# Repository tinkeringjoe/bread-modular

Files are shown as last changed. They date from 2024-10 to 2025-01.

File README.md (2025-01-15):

# Bread Modular
Bread Modular is an open-source hardware modular synthesizer format designed to be minimalistic and cost-effective.

Bread Modular
### Key Features

* **Modular Design:** Just like Eurorack
* **USB-Powered:** It can be portable
* **Minimal Design:** Cost Effective
* **Modular MIDI Support:** Use MIDI to communicate between modules (still supports CV & Gate)
* **Analog and Digital Signal Paths:** It’s your choice 
* **Diverse Built-in Modules:** Includes a wide range of pre-designed modules
* **Configurable Digital Modules:** Supports both voice and CV (uses AtTiny 1616 or ESP32)
* **Fully Open Source:** Including schematics, PCB designs, and code
* **Ease of Customization:** Enables straightforward creation of custom modules tailored to specific needs.
* **No Case Required:** Can be used directly on a breadboard or mounted on a simple base module.

## Table of Contents

* [Specification](https://github.com/bread-modular/bread-modular/wiki/Specification)
* [Common Parts](https://github.com/bread-modular/bread-modular/wiki/Common-Parts)
* [Modules](https://github.com/bread-modular/bread-modular/wiki/Modules)

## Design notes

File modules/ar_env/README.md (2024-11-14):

# AR ENV

A Simple Attack/Release Envelope.

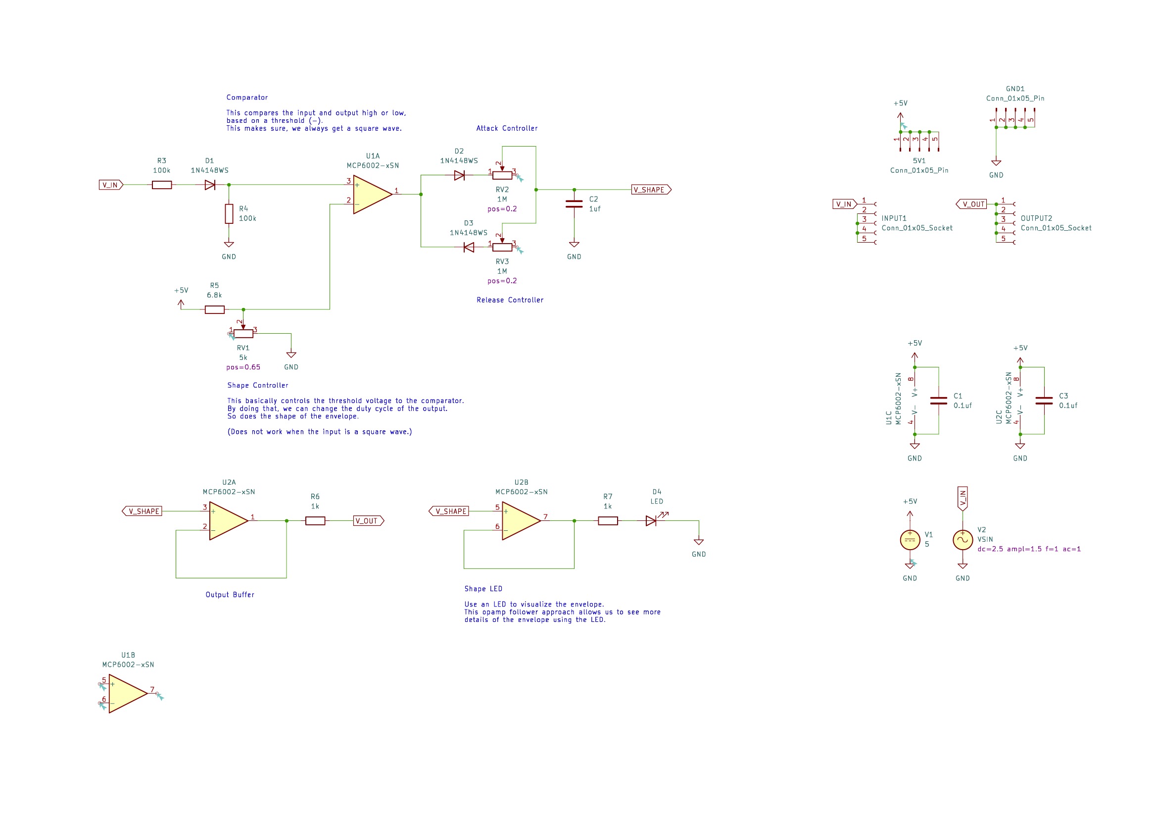
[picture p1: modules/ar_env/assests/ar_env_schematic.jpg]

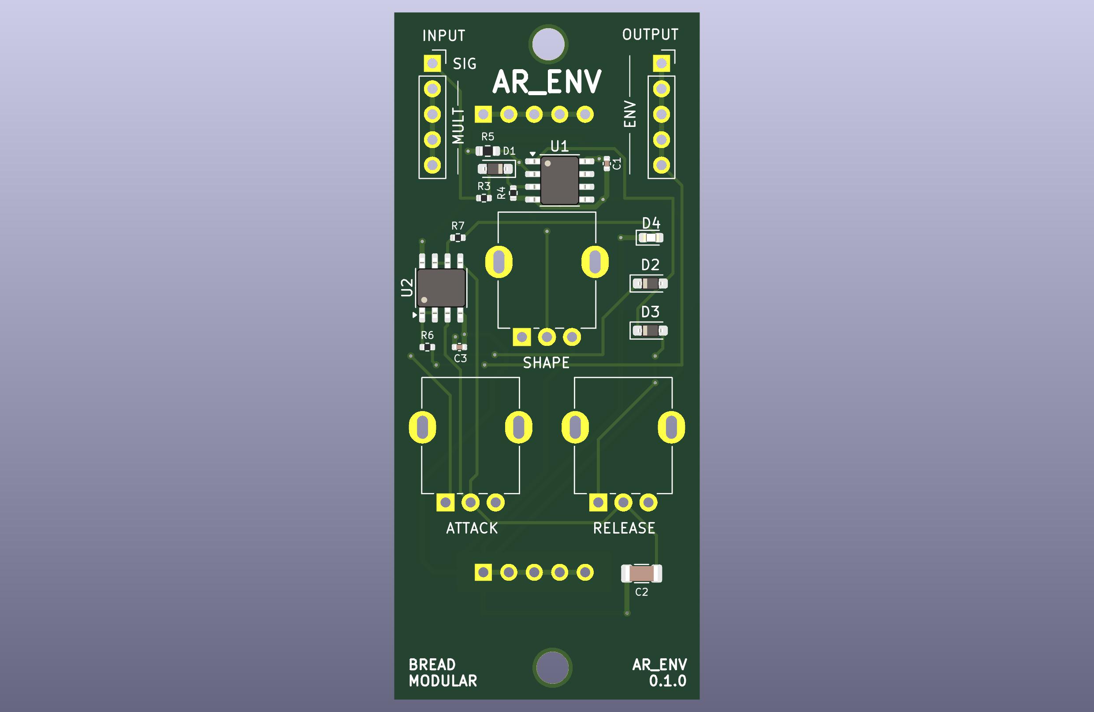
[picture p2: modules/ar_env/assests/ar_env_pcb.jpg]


This has three controls:

* Attack
* Release
* Shape - Controls the duty cycle. Only works when the "SIG" input is a triangle signal. 

> Make sure to keep the Shape at pos=0.5 when using the square wave inputs.

## Known Errors

* When the Attack & Release is close to zero, this module leaks some pops to the ground.
(So, it will pick up by the line-out)
* When the input is above 5Hz, it's very hard to control Attack & Release. (We need to wiggle between pos=0.0 & pos=0.2)
* Using with JVCA gives more controls, but it will be confusing sometimes. Especially JVCA has a built-in delay effect for changes.
(It could be a feature too)
A simple Vactral based VCA would fix it. (V2CA)

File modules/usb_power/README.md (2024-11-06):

# USB_Power

A simple power source from USB.

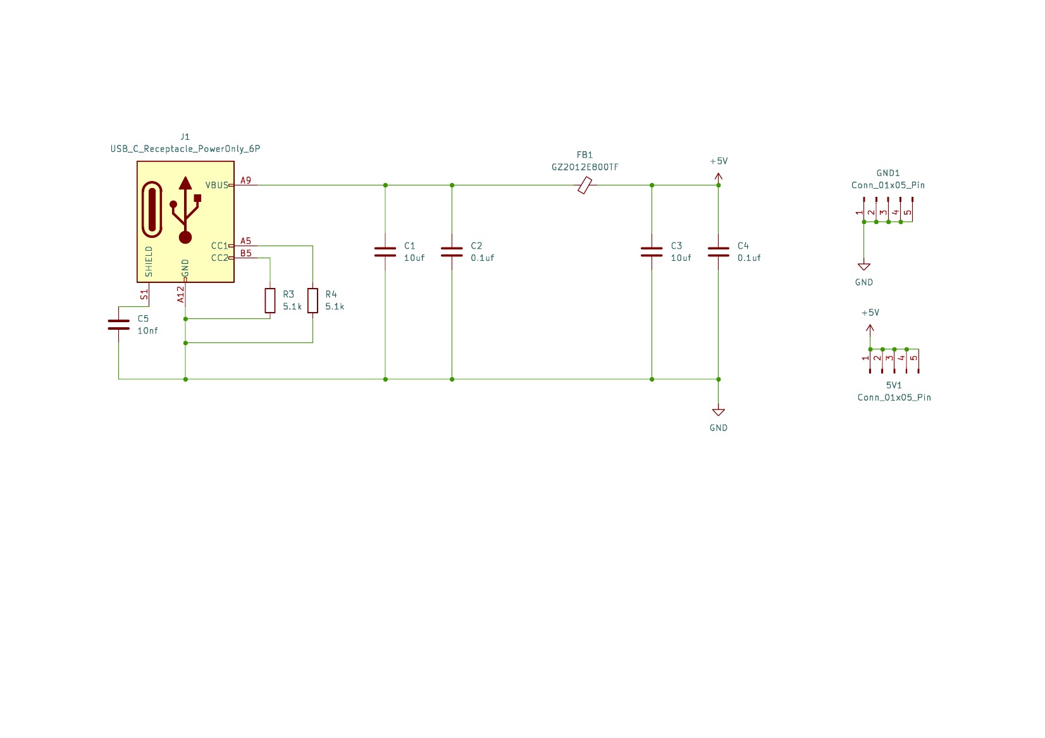
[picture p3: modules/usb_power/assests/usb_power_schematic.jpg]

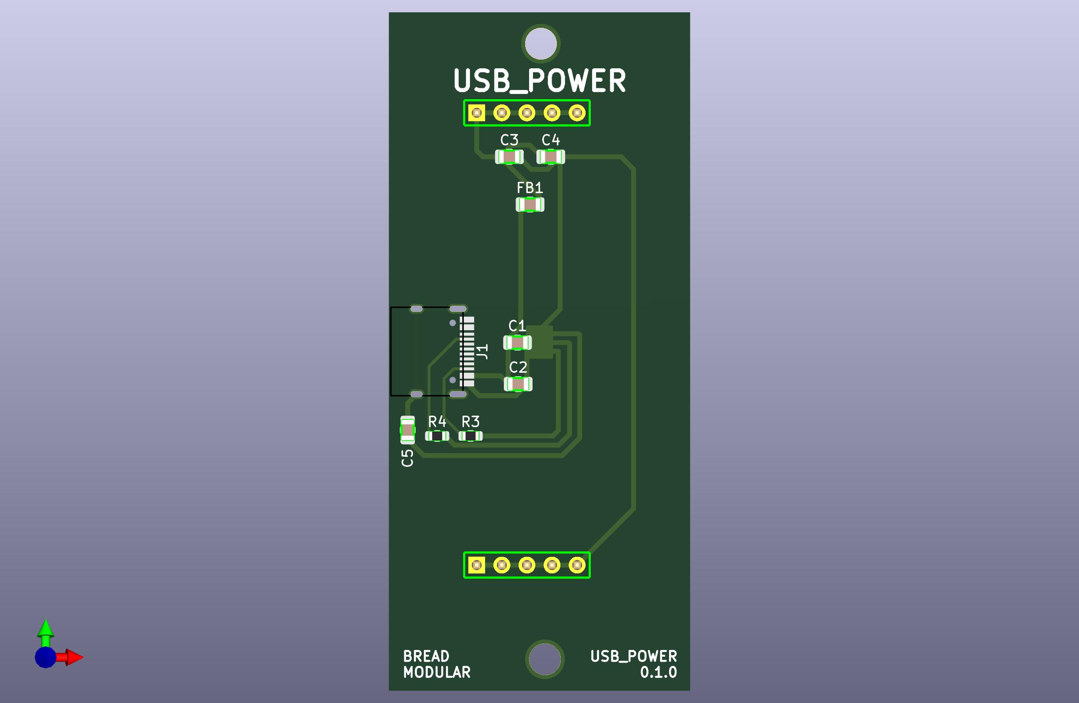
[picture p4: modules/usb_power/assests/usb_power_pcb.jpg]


## Usage

This plug a USB-C and now we have power to the system.<br/>
This makes is not only to get power from computer, but using bunch of power source including your phone. This will be the only power source we'll ever need.

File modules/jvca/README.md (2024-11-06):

# JVCA

JFET based VCA with bias and gain control.

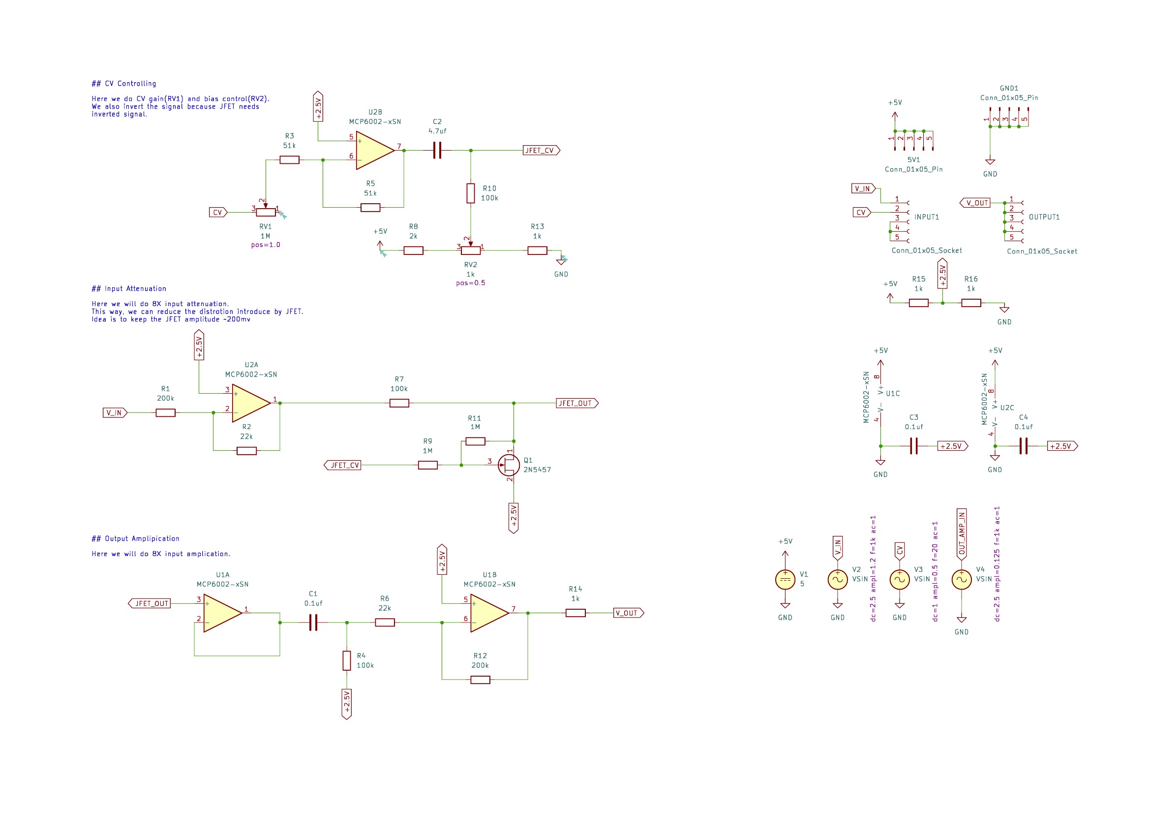
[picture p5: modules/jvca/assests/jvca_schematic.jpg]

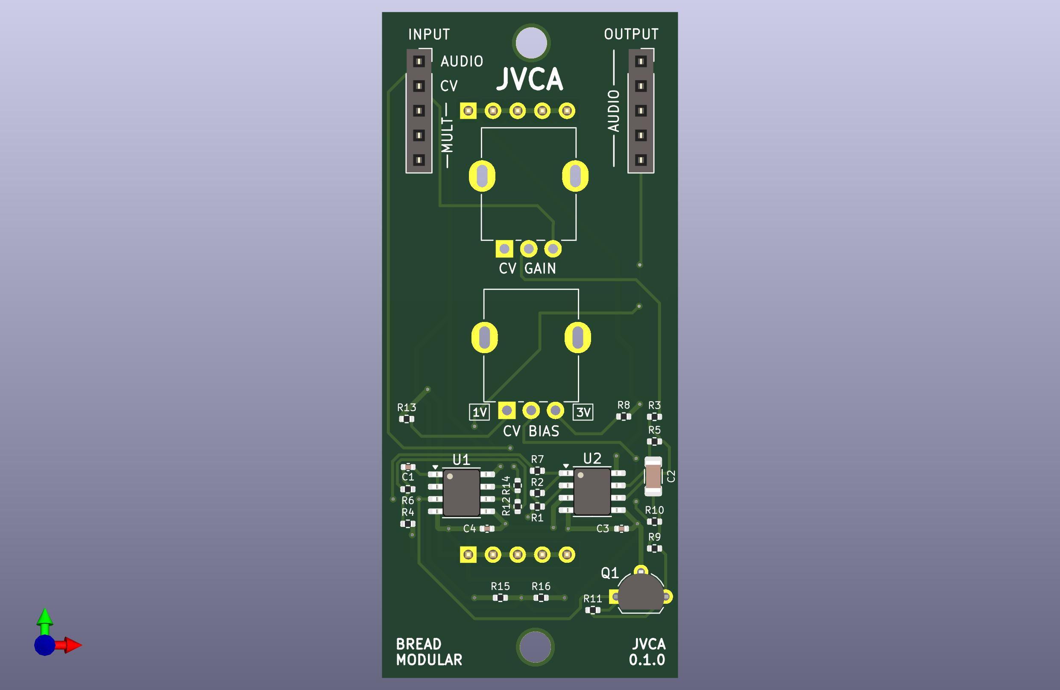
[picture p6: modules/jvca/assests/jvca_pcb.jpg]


## Usage

* We can control CV gain with the "CV GAIN" RV and minumum gain is 0.05 and maximum is 1.
* CV bias RV will change the CV bias from 1V to 3V range.
  * If it's 1V, audio is audible even with CV change.
  * If it's 3V, audio is not audible

* If we center the CV around 2V, 500mv amplitude is enough to cut through the audio.
* But we can play with these values to get interesting results

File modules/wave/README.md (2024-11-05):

# Wave

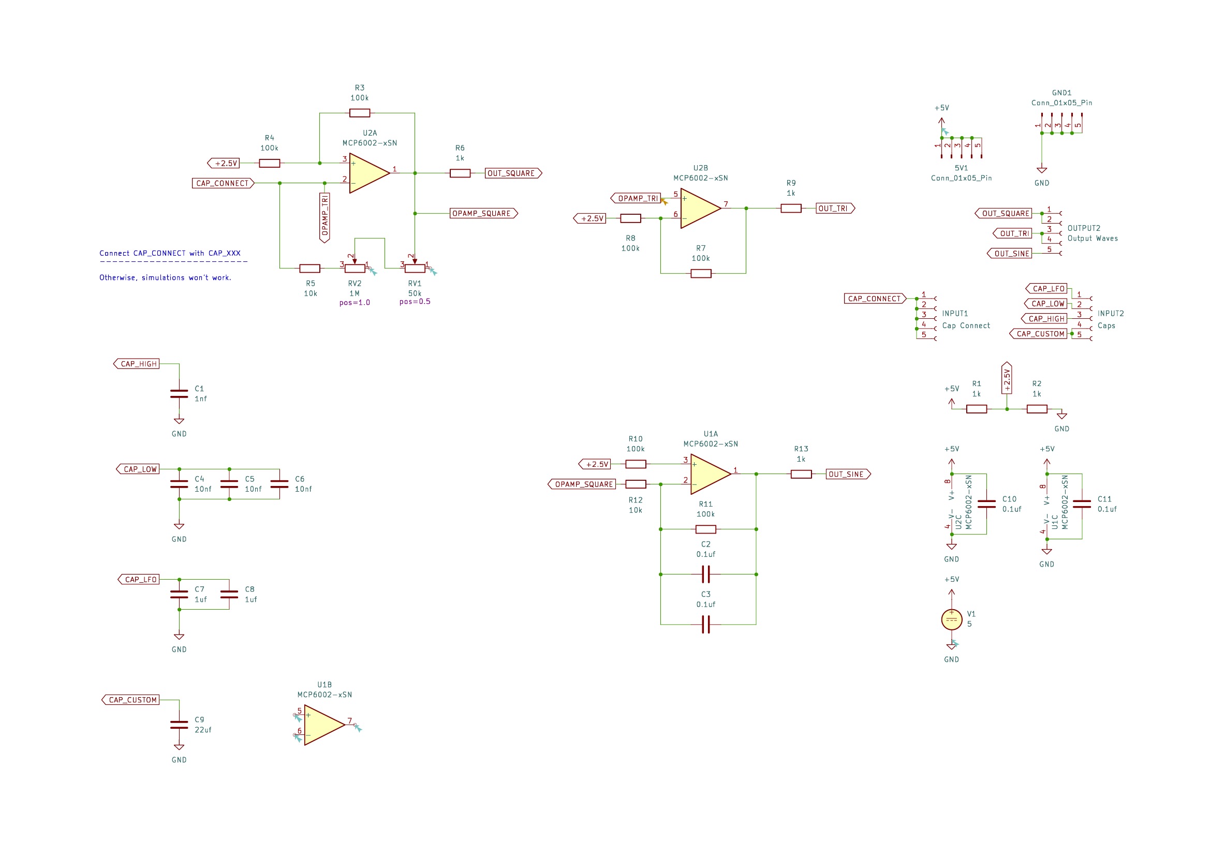
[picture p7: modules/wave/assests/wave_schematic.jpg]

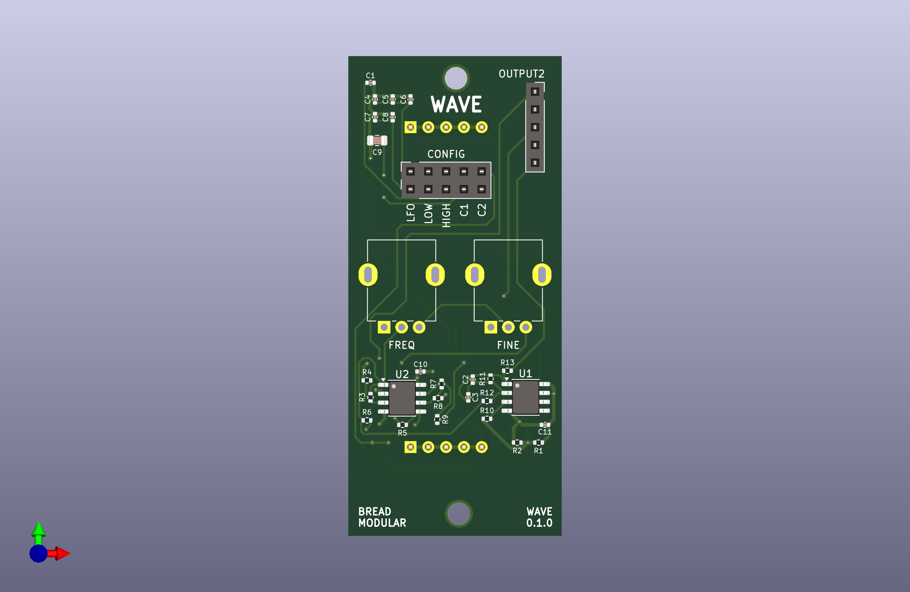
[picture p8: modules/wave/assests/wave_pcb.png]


A Simple Waveform generator based on opamp relaxation oscillators. It can generate:

* Square
* Triangle 
* Sine (only upword 45Hz)

## Configurations

Before we use this module, we need to configure and select the frequence range via the config jumping panel.

Here are the frequency ranges:

* LFO - 0.22Hz to 22Hz
* LOW - 15Hz to 1.5kHz
* HIGH - 227Hz to 22kHz
* C1 & C2 - Add custom capacitors
  (Resistance => Min: 10k, Max: 1M)

## Usage

You can select the frequency using "FREQ" potentiometer which is 1M ohms. Then you can fine tune it via the 50k ohms "FINE" potentiometer.

(Turning clockwise reduces the resistance)

## Notes

* Does not produce any results, when it's not configured
* Triangle waveform is appoximated & it's not a pure triangle
* Sine wave got distroted when the frequncy is below 45Hz
* Sine wave will be attenuated as the freq increases
* No voltage control input or modulation is supported

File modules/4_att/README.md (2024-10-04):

# 4_ATT

This is a 4 channel passive attenuator. 

<p float="left">
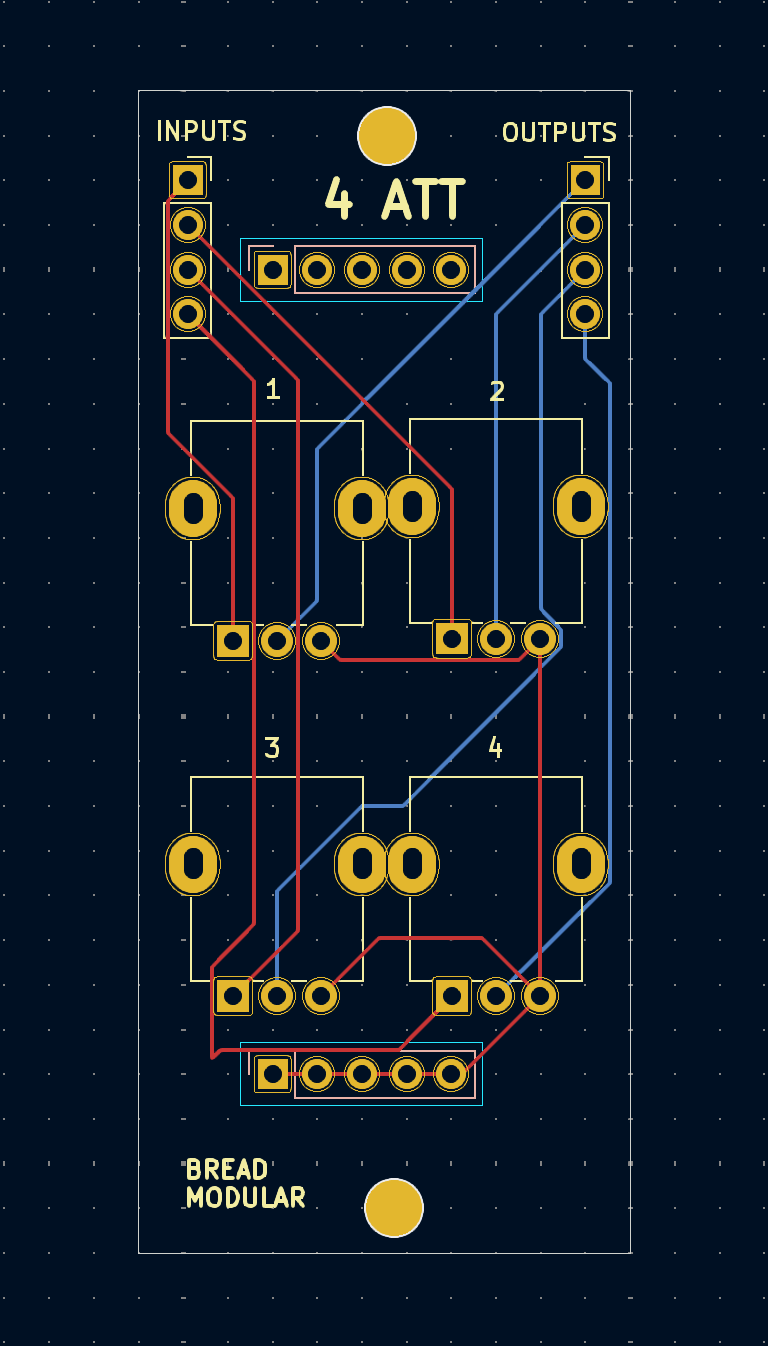
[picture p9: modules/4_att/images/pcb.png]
  
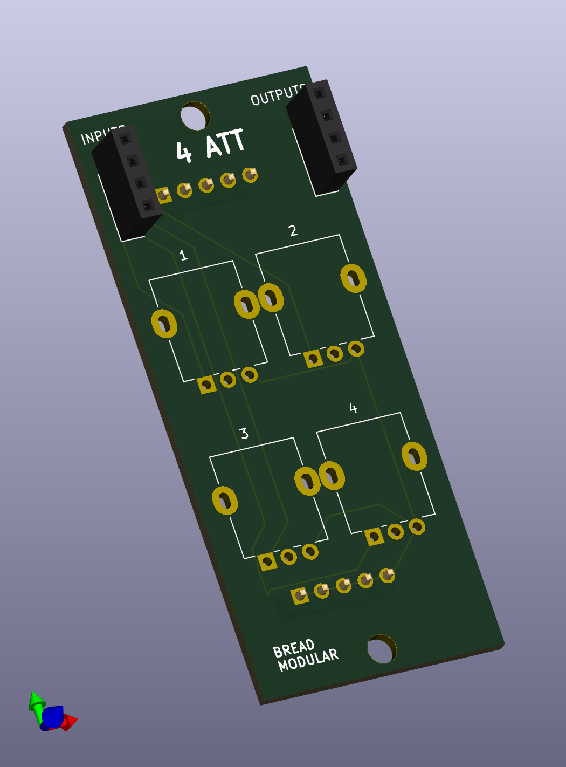
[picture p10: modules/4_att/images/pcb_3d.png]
   
</p>

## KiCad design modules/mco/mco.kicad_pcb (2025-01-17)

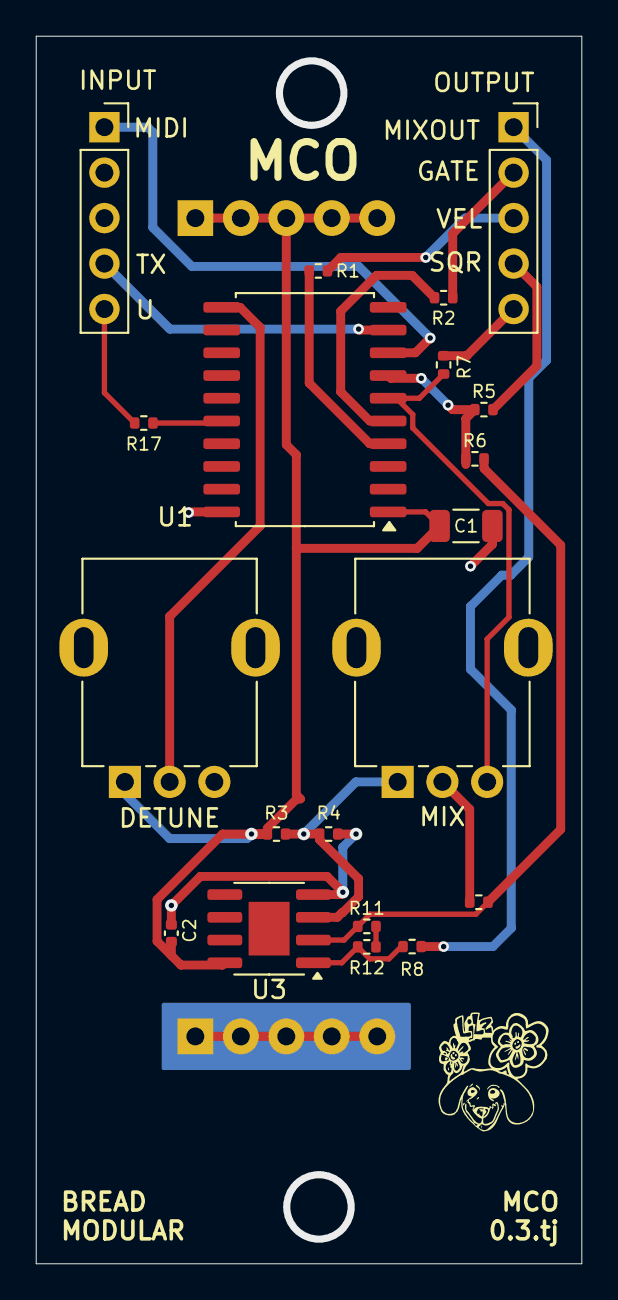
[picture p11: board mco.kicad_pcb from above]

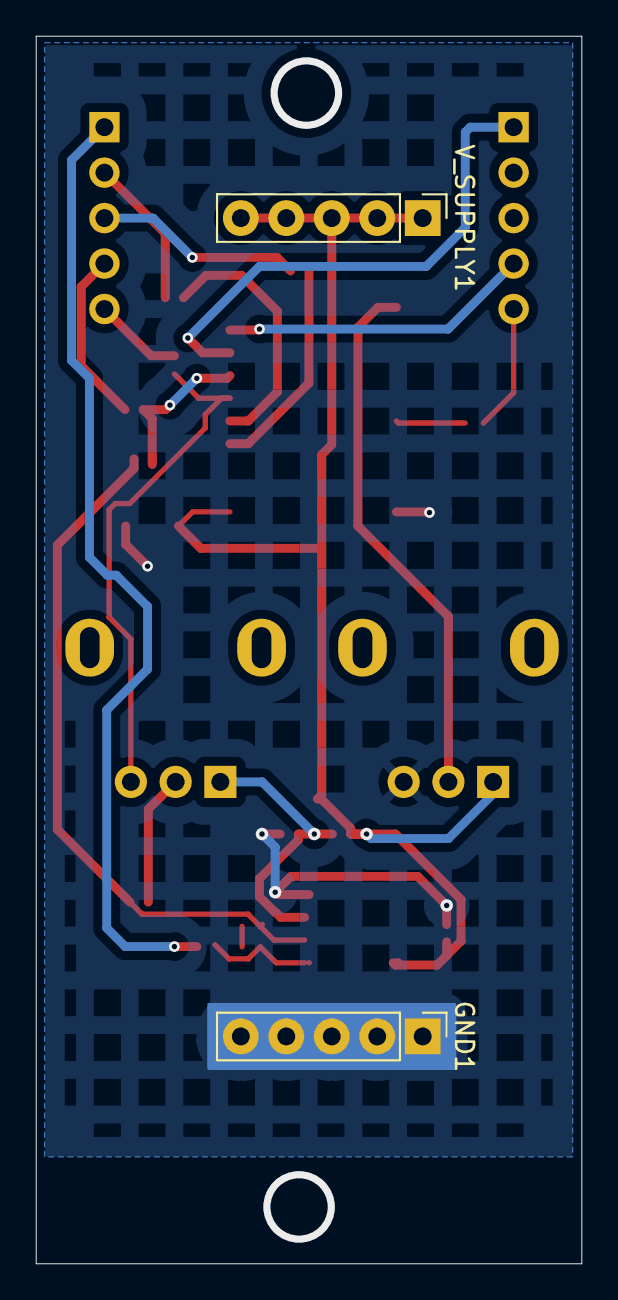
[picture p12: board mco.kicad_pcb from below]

Board: 2 copper layers, 30.5 x 68.6 mm, 22 parts (2 on the bottom side), 21 nets.

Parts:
C1: 100uf; C_1206_3216Metric
C2: 0.1uf; C_0402_1005Metric
GND1: Conn_01x05_Pin; Power_Connector
INPUT1: Conn_01x05_Socket; PinSocket_1x05_P2.54mm_Vertical
OUTPUT1: Conn_01x05_Socket; PinSocket_1x05_P2.54mm_Vertical
R1, R2, R3, R4, R5, R7, R8: 1k; R_0402_1005Metric
R6, R10: 1M; R_0402_1005Metric
R11, R12: 200k; R_0402_1005Metric
R17: 4.7k; R_0402_1005Metric
RV1, RV2: 50k; Potentiometer_RV09
U1: ATtiny1616-S; SOIC-20W_7.5x12.8mm_P1.27mm
U3: MCP6002-xSN; SOIC-8-1EP_3.9x4.9mm_P1.27mm_EP2.29x3mm
V_SUPPLY1: Conn_01x05_Pin; Power_Connector

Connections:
DETUNED_OUT: OUTPUT1.5, R7.2
DETUNED_TONE: R7.1, RV2.3, U1.6 (PB5)
FUNDAMENTAL_TONE: R5.1, R6.1, U1.7 (PB4)
GATE: OUTPUT1.2, R2.2
GND: C1.1, C2.2, GND1.1, GND1.2, GND1.3, GND1.4, GND1.5, R4.2, RV1.3, U1.20 (GND), U3.4 (V-)
MIDI: INPUT1.1, U1.8 (PB3)
MIX_OUT: OUTPUT1.1, R8.2
unnamed: R10.1, RV2.2
unnamed: R11.2, R12.1
unnamed: R8.1, R12.2, U3.1
unnamed: R1.1, U1.4 (PA6)
unnamed: R2.1, U1.5 (PA7)
unnamed: R17.1, U1.16 (~RESET/PA0)
unnamed: R6.2, R10.2, R11.1, U3.2 (-)
SQUARE_OUT: OUTPUT1.4, R5.2
TX: INPUT1.4, U1.9 (PB2)
UDPI: INPUT1.5, R17.2
VELOCITY: OUTPUT1.3, R1.2
V_DETUNED: RV1.2, U1.11 (PB0)
V_MID: R3.2, R4.1, RV2.1, U3.3 (+)
V_SUPPLY: C1.2, C2.1, R3.1, RV1.1, U1.1 (VCC), U3.8 (V+), V_SUPPLY1.1, V_SUPPLY1.2, V_SUPPLY1.3, V_SUPPLY1.4, V_SUPPLY1.5

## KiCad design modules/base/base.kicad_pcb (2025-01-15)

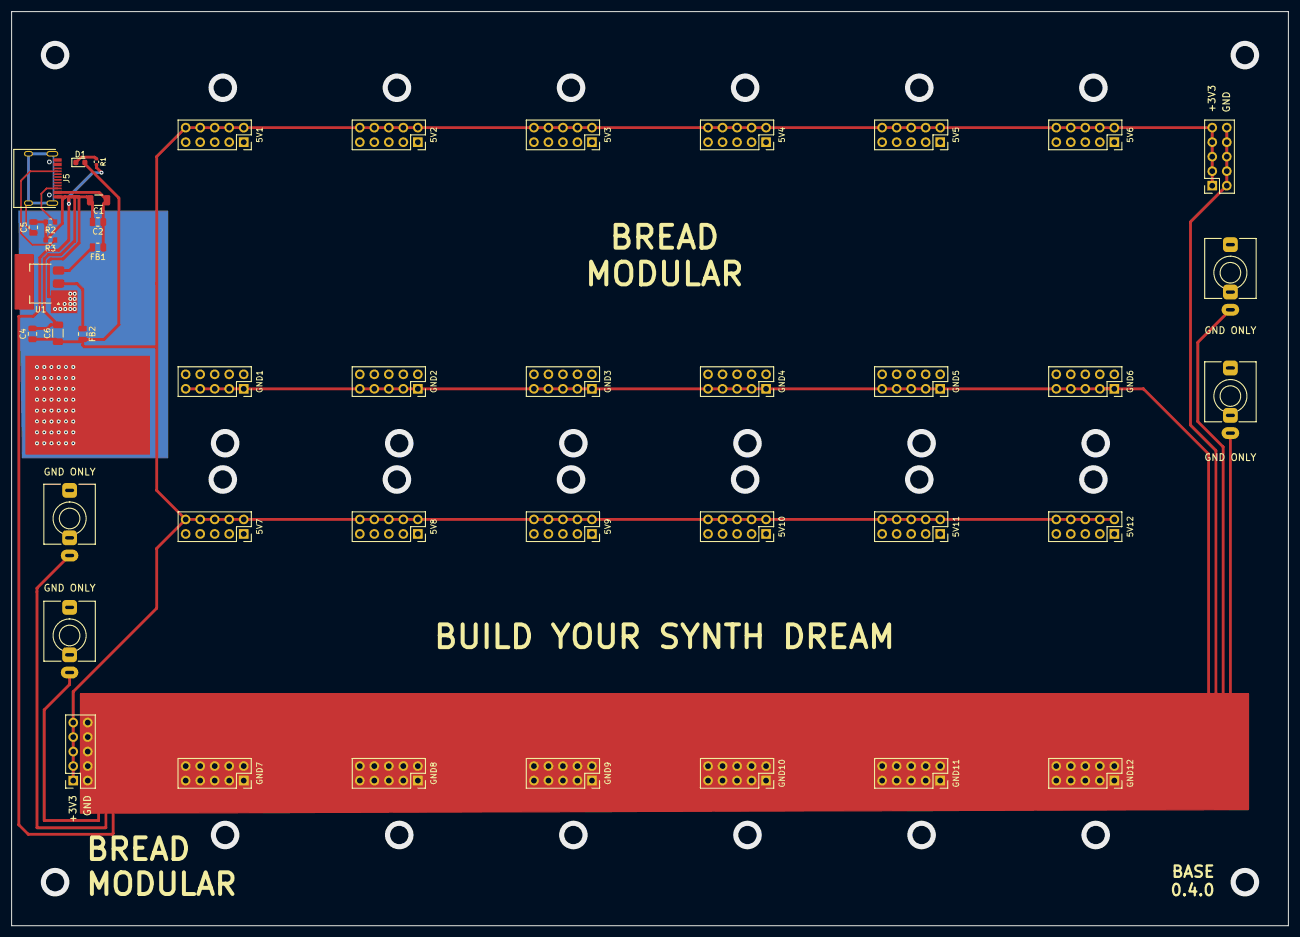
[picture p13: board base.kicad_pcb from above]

Board: 2 copper layers, 223.5 x 160.0 mm, 43 parts (0 on the bottom side), 9 nets.

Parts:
5V1, 5V2, 5V3, 5V4, 5V5, 5V6, 5V7, 5V8, 5V9, 5V10, 5V11, 5V12, 5V13, 5V14: Conn_02x05_Socket; PinSocket_2x05_P2.54mm_Vertical
C1, C6: 100uf; C_1206_3216Metric
C2, C4: 0.1uf; C_0805_2012Metric
C5: 10nf; C_0805_2012Metric
D1: LED; LED_0603_1608Metric
FB1, FB2: GZ2012E800TF; C_0805_2012Metric
GND1, GND2, GND3, GND4, GND5, GND6, GND7, GND8, GND9, GND10, GND11, GND12: Conn_02x05_Socket; PinSocket_2x05_P2.54mm_Vertical
J1, J2, J3, J4: Ground; Jack_3.5mm_QingPu_WQP-PJ366ST_Vertical
J5: USB_C_Receptacle_PowerOnly_6P; HRO-TYPE-C-31-M-12
R1: 1k; R_0402_1005Metric
R2, R3: 5.1k; R_0603_1608Metric
U1: AMS1117-3.3; SOT-223

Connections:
+3.3V: 5V1.2, 5V1.4, 5V1.6, 5V1.8, 5V1.10, 5V2.2, 5V2.4, 5V2.6, 5V2.8, 5V2.10, 5V3.2, 5V3.4, 5V3.6, 5V3.8, 5V3.10, 5V4.2, 5V4.4, 5V4.6, 5V4.8, 5V4.10, 5V5.2, 5V5.4, 5V5.6, 5V5.8, 5V5.10, 5V6.2, 5V6.4, 5V6.6, 5V6.8, 5V6.10, 5V7.2, 5V7.4, 5V7.6, 5V7.8, 5V7.10, 5V8.2, 5V8.4, 5V8.6, 5V8.8, 5V8.10, 5V9.2, 5V9.4, 5V9.6, 5V9.8, 5V9.10, 5V10.2, 5V10.4, 5V10.6, 5V10.8, 5V10.10, 5V11.2, 5V11.4, 5V11.6, 5V11.8, 5V11.10, 5V12.2, 5V12.4, 5V12.6, 5V12.8, 5V12.10, 5V13.1, 5V13.3, 5V13.5, 5V13.7, 5V13.9, 5V14.1, 5V14.3, 5V14.5, 5V14.7, 5V14.9, C4.1, C6.1, D1.2 (A), FB2.2
+5V: C1.1, C2.1, FB1.1, J5.A9 (VBUS)
GND: 5V13.2, 5V13.4, 5V13.6, 5V13.8, 5V13.10, 5V14.2, 5V14.4, 5V14.6, 5V14.8, 5V14.10, C1.2, C2.2, C4.2, C5.2, C6.2, GND1.1, GND1.3, GND1.5, GND1.7, GND1.9, GND2.1, GND2.3, GND2.5, GND2.7, GND2.9, GND3.1, GND3.3, GND3.5, GND3.7, GND3.9, GND4.1, GND4.3, GND4.5, GND4.7, GND4.9, GND5.1, GND5.3, GND5.5, GND5.7, GND5.9, GND6.1, GND6.3, GND6.5, GND6.7, GND6.9, GND7.1, GND7.2, GND7.3, GND7.4, GND7.5, GND7.6, GND7.7, GND7.8, GND7.9, GND7.10, GND8.1, GND8.2, GND8.3, GND8.4, GND8.5, GND8.6, GND8.7, GND8.8, GND8.9, GND8.10, GND9.1, GND9.2, GND9.3, GND9.4, GND9.5, GND9.6, GND9.7, GND9.8, GND9.9, GND9.10, GND10.1, GND10.2, GND10.3, GND10.4, GND10.5, GND10.6, GND10.7, GND10.8, GND10.9, GND10.10, GND11.1, GND11.2, GND11.3, GND11.4, GND11.5, GND11.6, GND11.7, GND11.8, GND11.9, GND11.10, GND12.1, GND12.2, GND12.3, GND12.4, GND12.5, GND12.6, GND12.7, GND12.8, GND12.9, GND12.10, J1.S, J2.S, J3.S, J4.S, J5.A12 (GND), R1.2, R2.2, R3.2, U1.1 (GND)
unnamed: D1.1 (K), R1.1
unnamed: J5.A5 (CC1), R3.1
unnamed: J5.B5 (CC2), R2.1
unnamed: C5.1, J5.S1 (SHIELD)
unnamed: FB1.2, U1.3 (VI)
unnamed: FB2.1, U1.2 (VO)

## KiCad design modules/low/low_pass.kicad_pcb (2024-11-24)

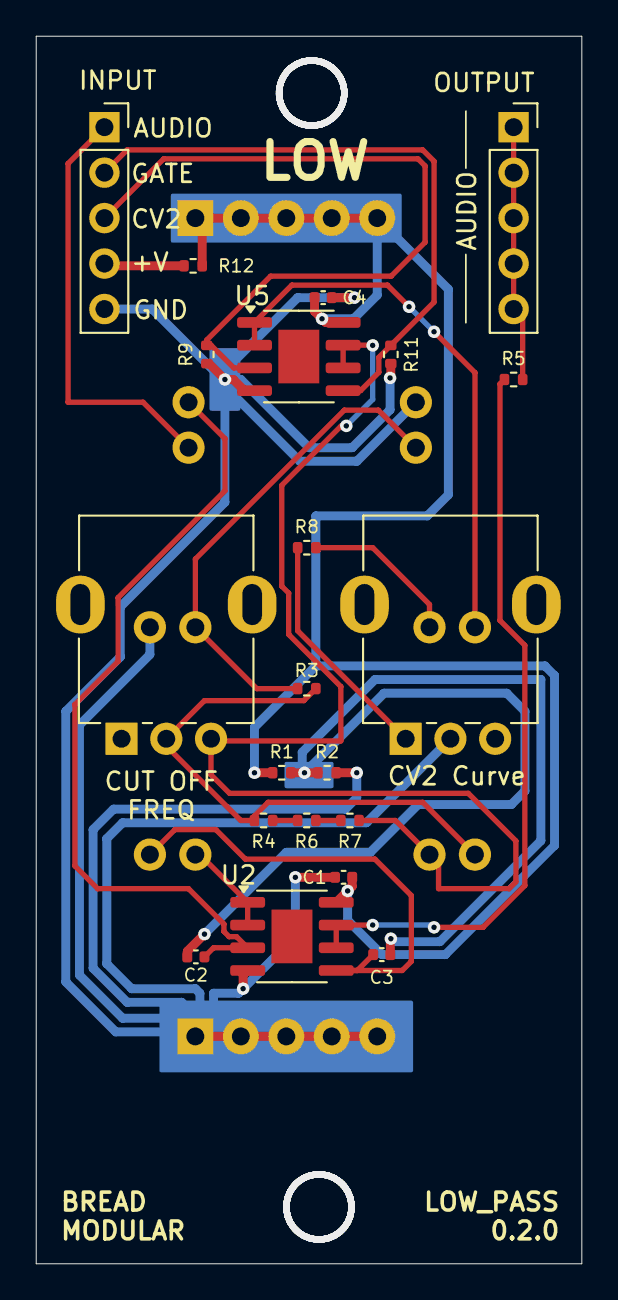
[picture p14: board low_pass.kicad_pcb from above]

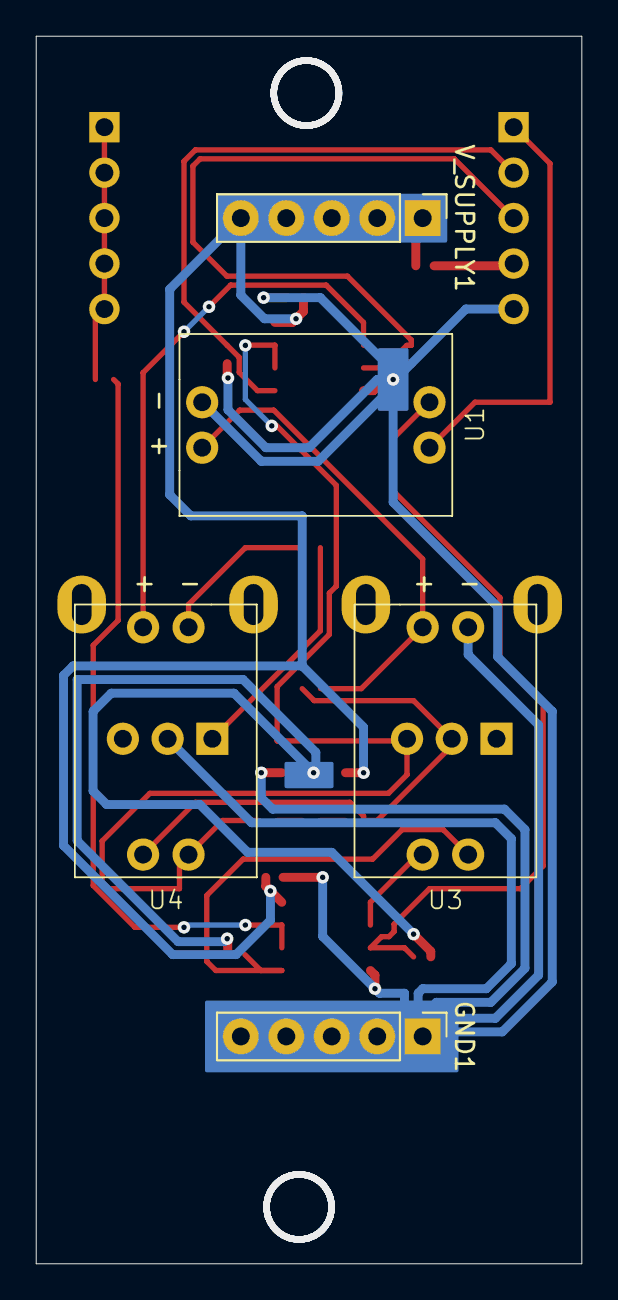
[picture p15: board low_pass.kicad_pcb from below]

Board: 2 copper layers, 30.5 x 68.6 mm, 26 parts (5 on the bottom side), 20 nets.

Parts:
C1, C4: 0.1uf; C_0402_1005Metric
C2, C3: 10nf; C_0402_1005Metric
GND1: Conn_01x05_Pin; Power_Connector
INPUT1: Conn_01x05_Socket; PinSocket_1x05_P2.54mm_Vertical
OUTPUT1: Conn_01x05_Socket; PinSocket_1x05_P2.54mm_Vertical
R1, R2, R5: 1k; R_0402_1005Metric
R3, R8: 560; R_0402_1005Metric
R4, R6, R7: 200k; R_0402_1005Metric
R9, R11: 1M; R_0402_1005Metric
R12: 10k; R_0402_1005Metric
RV1, RV2: 1M; Potentiometer_RV09
U1, U3, U4: VTL5C
U2, U5: MCP6002-xSN; SOIC-8-1EP_3.9x4.9mm_P1.27mm_EP2.29x3mm
V_SUPPLY1: Conn_01x05_Pin; Power_Connector

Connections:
AUDIO_IN: INPUT1.1, U1.4
AUDIO_OUT: OUTPUT1.1, OUTPUT1.2, OUTPUT1.3, OUTPUT1.4, OUTPUT1.5, R5.2
CUT_OFF_CV: INPUT1.3, R9.2, U5.3 (+)
GATE_CV: INPUT1.2, R11.2, U5.5 (+)
GND: C1.2, C4.2, GND1.1, GND1.2, GND1.3, GND1.4, GND1.5, INPUT1.5, R2.2, R9.1, R11.1, RV2.2, U1.1 (-), U2.4 (V-), U3.1 (-), U5.4 (V-)
unnamed: INPUT1.4, R12.2
unnamed: R3.2, R4.2, RV1.2, U4.4
unnamed: R4.1, R6.2
unnamed: R6.1, R7.2
unnamed: R8.1, RV2.1
unnamed: R3.1, U1.2 (+), U3.2 (+)
unnamed: C2.1, U1.3, U2.3 (+)
unnamed: U2.1, U2.2 (-), U3.4
unnamed: C3.1, U2.5 (+), U3.3
unnamed: R5.1, U2.6 (-), U2.7
unnamed: U4.2 (+), U5.1, U5.2 (-)
unnamed: R8.2, U4.1 (-)
unnamed: R7.1, RV1.3, U4.3, U5.6 (-), U5.7
V_MID: C2.2, C3.2, R1.2, R2.1
V_SUPPLY: C1.1, C4.1, R1.1, R12.1, U2.8 (V+), U5.8 (V+), V_SUPPLY1.1, V_SUPPLY1.2, V_SUPPLY1.3, V_SUPPLY1.4, V_SUPPLY1.5

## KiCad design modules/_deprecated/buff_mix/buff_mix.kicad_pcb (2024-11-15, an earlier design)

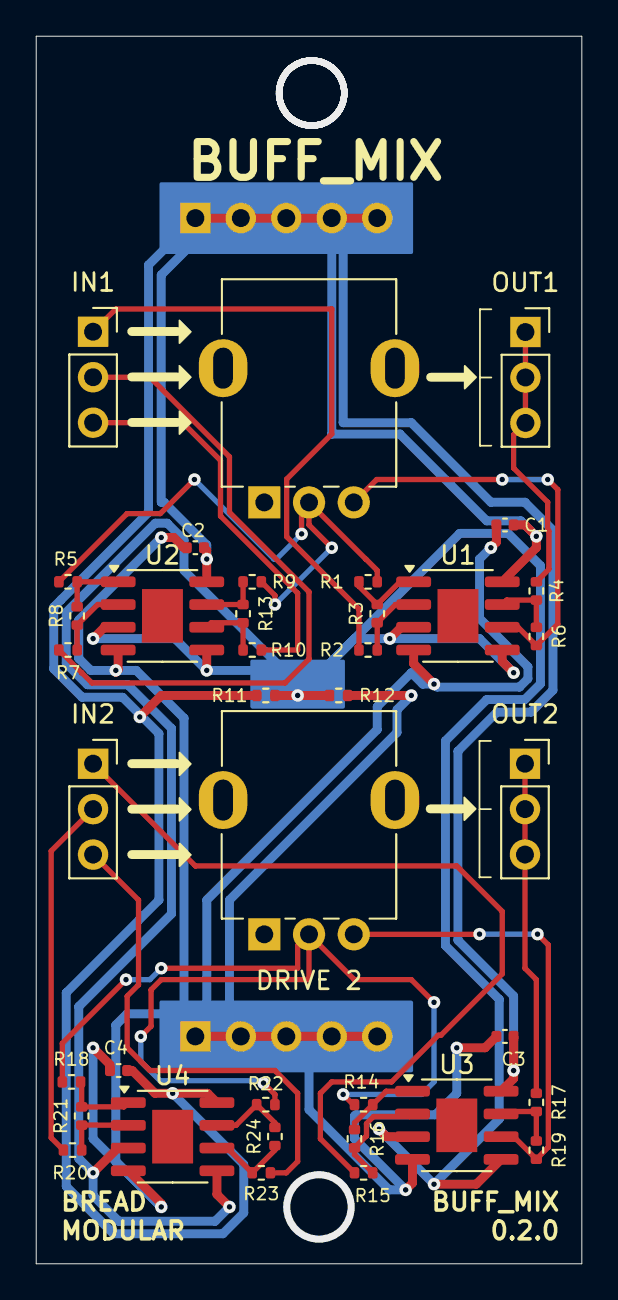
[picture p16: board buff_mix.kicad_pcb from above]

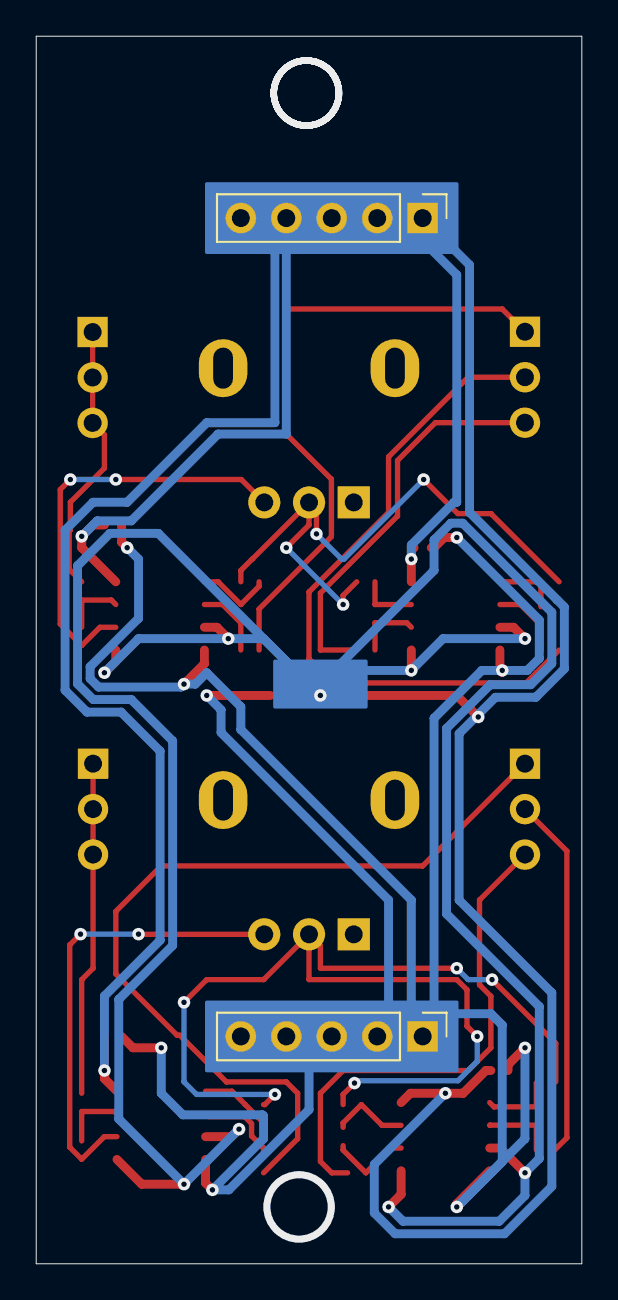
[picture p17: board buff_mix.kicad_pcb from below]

Board: 2 copper layers, 30.5 x 68.6 mm, 40 parts (2 on the bottom side), 29 nets.

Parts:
5V1: Conn_01x05_Pin; PinHeader_1x05_P2.54mm_Vertical
C1, C2, C3, C4: 0.1uf; C_0402_1005Metric
GND1: Conn_01x05_Pin; PinHeader_1x05_P2.54mm_Vertical
IN1, IN2: Conn_01x03_Socket; PinSocket_1x03_P2.54mm_Vertical
OUT1, OUT2: Conn_01x03_Socket; PinSocket_1x03_P2.54mm_Vertical
R1, R2, R3, R5, R6, R7, R8, R9, R10, R13, R14, R15, R16, R18, R19, R20, R21, R22, R23, R24: 1M; R_0402_1005Metric
R4, R11, R12, R17: 1k; R_0402_1005Metric
RV1, RV2: 1M; Potentiometer_RV09
U1, U2, U3, U4: MCP6002-xSN; SOIC-8-1EP_3.9x4.9mm_P1.27mm_EP2.29x3mm

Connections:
+2.5V: R11.2, R12.1, U1.3 (+), U1.5 (+), U2.3 (+), U2.5 (+), U3.3 (+), U3.5 (+), U4.3 (+), U4.5 (+)
+5V: 5V1.1, 5V1.2, 5V1.3, 5V1.4, 5V1.5, C1.1, C2.1, C3.1, C4.1, R11.1, U1.8 (V+), U2.8 (V+), U3.8 (V+), U4.8 (V+)
GND: C1.2, C2.2, C3.2, C4.2, GND1.1, GND1.2, GND1.3, GND1.4, GND1.5, R12.2, U1.4 (V-), U2.4 (V-), U3.4 (V-), U4.4 (V-)
INA_1: IN1.1, R2.1
INA_2: IN1.2, R7.1
INA_3: IN1.3, R10.1
INB_1: IN2.1, R15.1
INB_2: IN2.2, R20.1
INB_3: IN2.3, R23.1
unnamed: R1.1, R3.2, U1.1
unnamed: R1.2, R5.2, R9.2, RV1.2
unnamed: R4.1, R6.2, U1.7
unnamed: R5.1, R8.2, U2.1
unnamed: R9.1, R13.2, U2.7
unnamed: R14.1, R16.2, U3.1
unnamed: R14.2, R18.2, R22.2, RV2.2
unnamed: R17.1, R19.2, U3.7
unnamed: R18.1, R21.2, U4.1
unnamed: R22.1, R24.2, U4.7
unnamed: R2.2, R3.1, U1.2 (-)
unnamed: R6.1, RV1.3, U1.6 (-)
unnamed: R7.2, R8.1, U2.2 (-)
unnamed: R10.2, R13.1, U2.6 (-)
unnamed: R15.2, R16.1, U3.2 (-)
unnamed: R19.1, RV2.3, U3.6 (-)
unnamed: R20.2, R21.1, U4.2 (-)
unnamed: R23.2, R24.1, U4.6 (-)
OUTA: OUT1.1, OUT1.2, OUT1.3, R4.2
OUTB: OUT2.1, OUT2.2, OUT2.3, R17.2

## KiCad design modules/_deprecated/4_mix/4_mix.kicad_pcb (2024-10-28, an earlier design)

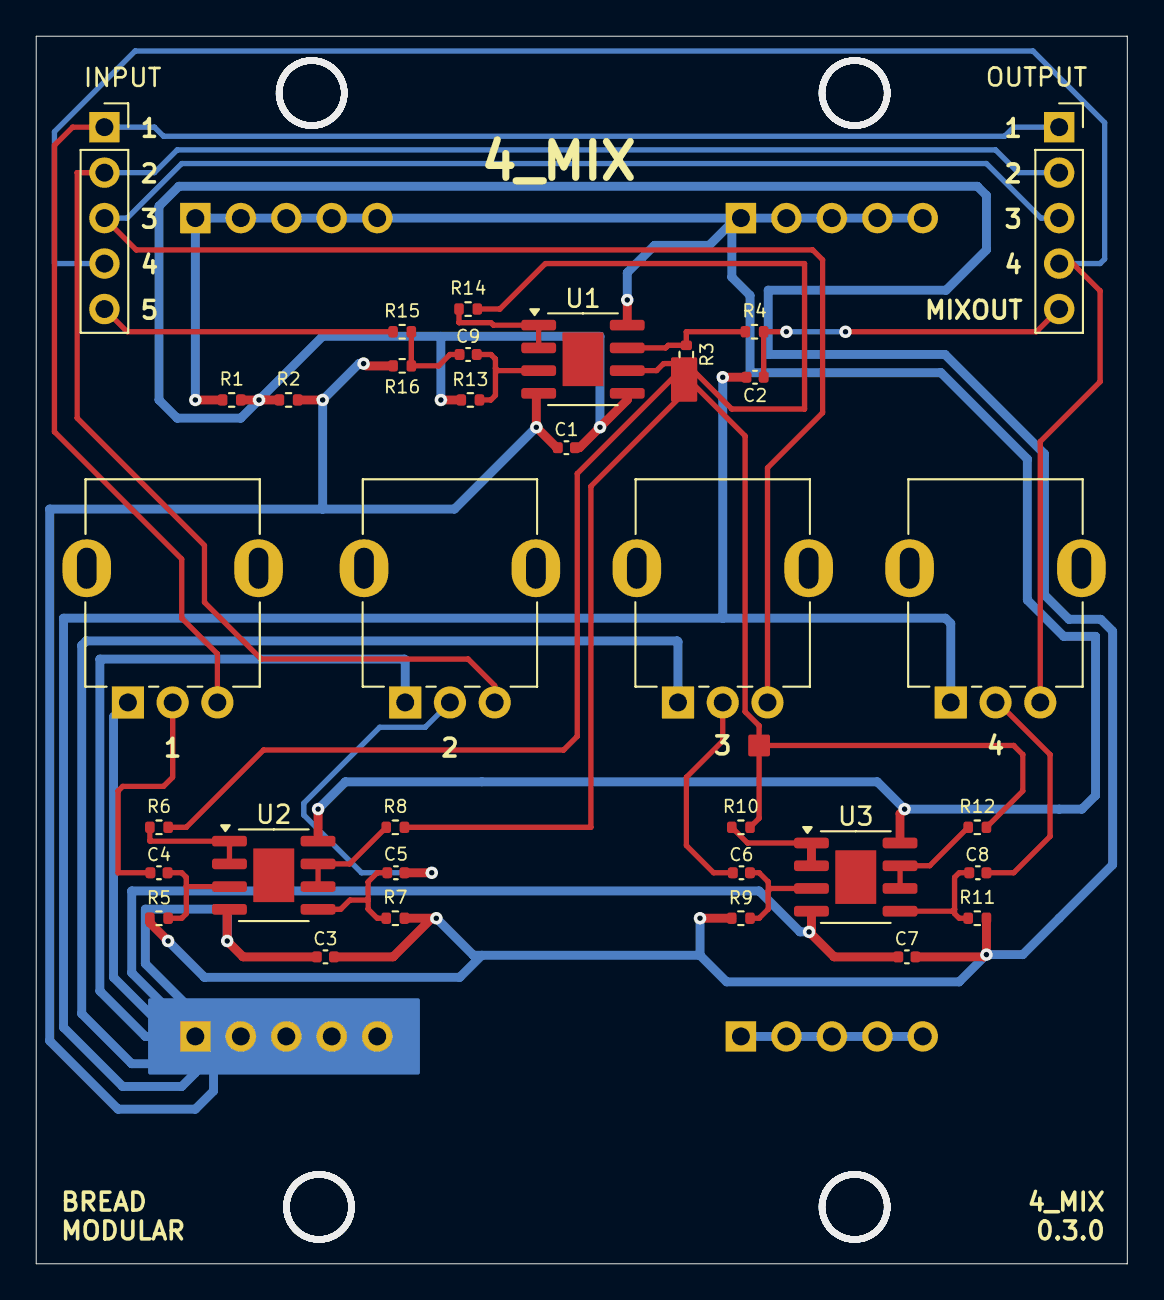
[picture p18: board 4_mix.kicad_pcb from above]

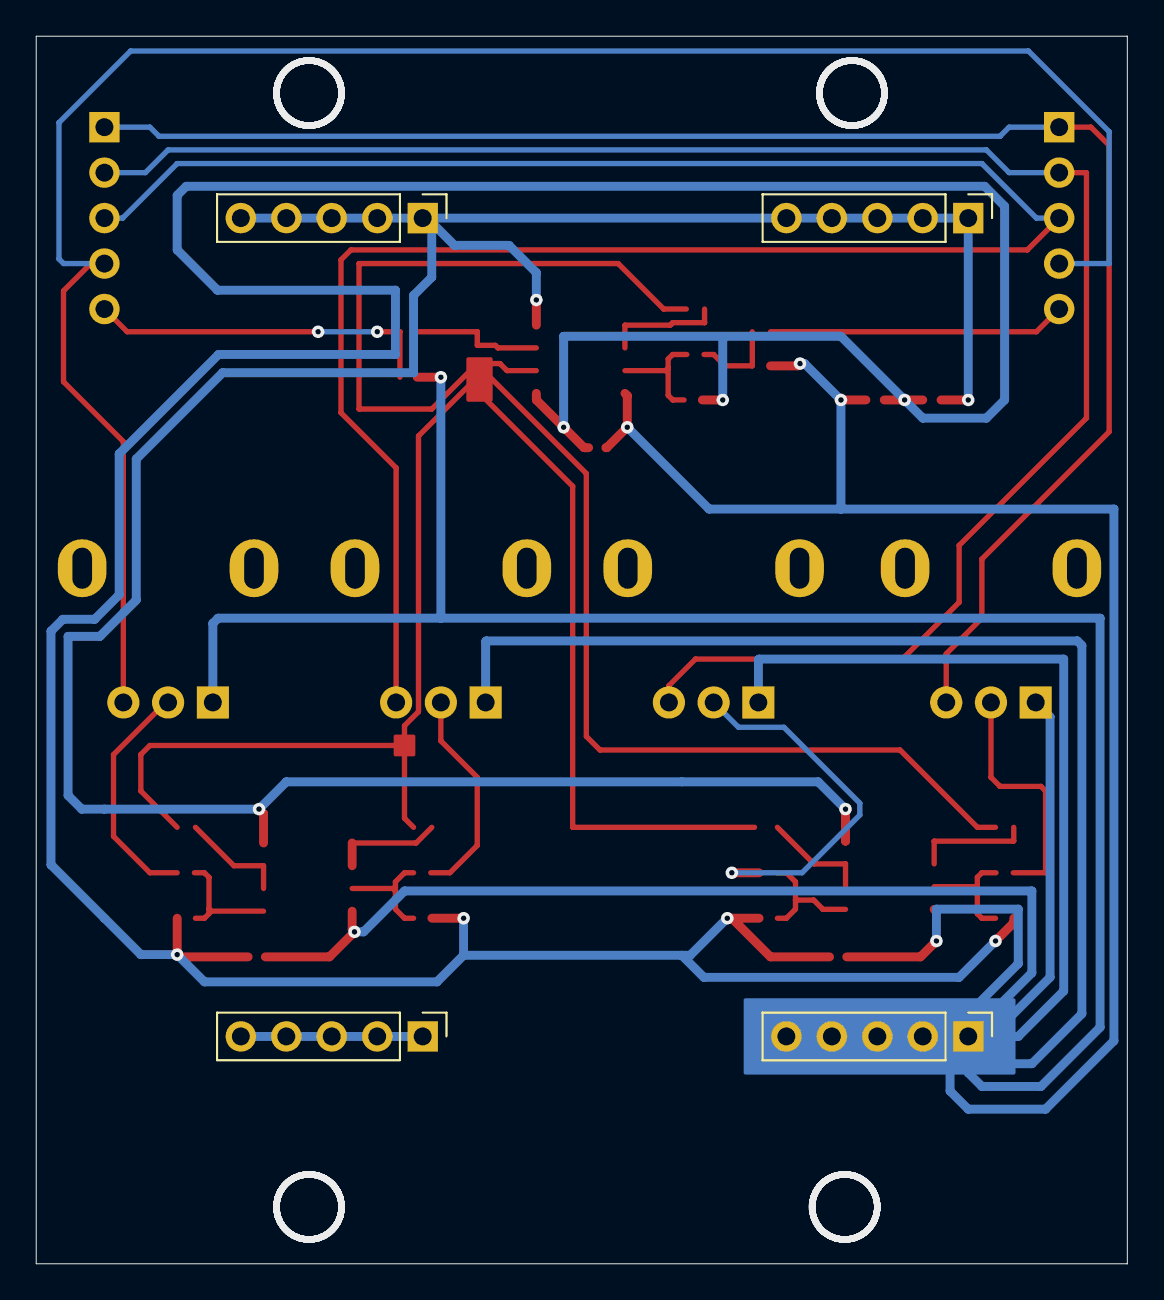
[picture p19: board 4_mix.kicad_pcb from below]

Board: 2 copper layers, 61.0 x 68.6 mm, 38 parts (4 on the bottom side), 27 nets.

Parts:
1, 2, 3, 4: 50k; Potentiometer_RV09
5V1, 5V2: Conn_01x05_Pin; PinHeader_1x05_P2.54mm_Vertical
C1, C3, C4, C5, C6, C7, C8, C9: 0.1uf; C_0402_1005Metric
C2: 0.01uf; C_0402_1005Metric
GND1, GND2: Conn_01x05_Pin; PinHeader_1x05_P2.54mm_Vertical
INPUT: Conn_01x05_Socket; PinSocket_1x05_P2.54mm_Vertical
OUTPUT: Conn_01x05_Socket; PinSocket_1x05_P2.54mm_Vertical
R1, R2, R4, R15: 1k; R_0402_1005Metric
R3, R5, R6, R7, R8, R9, R10, R11, R12, R13, R14: 100k; R_0402_1005Metric
R16: 51k; R_0402_1005Metric
U1, U2, U3: MCP6002; SOIC-8-1EP_3.9x4.9mm_P1.27mm_EP2.29x3mm

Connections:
2.5V: C1.2, C3.2, C7.2, R1.2, R2.1, R5.2, R7.2, R9.2, R11.2, R13.2, U1.5 (+)
+5V: 5V1.1, 5V1.2, 5V1.3, 5V1.4, 5V1.5, 5V2.1, 5V2.2, 5V2.3, 5V2.4, 5V2.5, R1.1, U1.8 (V+), U2.8 (V+), U3.8 (V+)
GND: 1.1, 2.1, 3.1, 4.1, C1.1, C2.2, C3.1, C7.1, GND1.1, GND1.2, GND1.3, GND1.4, GND1.5, R2.2, R16.2, U1.4 (V-), U2.4 (V-), U3.4 (V-)
IN_1: 1.3, INPUT.1, OUTPUT.1
IN_2: 2.3, INPUT.2, OUTPUT.2
IN_3: 3.3, INPUT.3, OUTPUT.3
IN_4: 4.3, INPUT.4, OUTPUT.4
IN_5: INPUT.5, R15.1
MIXOUT: C2.1, OUTPUT.5, R4.2
unnamed: 1.2, C4.1
unnamed: 2.2, C5.1
unnamed: 3.2, C6.1
unnamed: 4.2, C8.1
unnamed: C9.1, R15.2, R16.1
unnamed: GND2.1, GND2.2, GND2.3, GND2.4, GND2.5
unnamed: R3.2, R4.1, U1.7
unnamed: C9.2, R13.1, U1.3 (+)
unnamed: R3.1, R6.2, R8.2, R10.2, R12.2, R14.2, U1.6 (-)
unnamed: C4.2, R5.1, U2.3 (+)
unnamed: R6.1, U2.1, U2.2 (-)
unnamed: C5.2, R7.1, U2.5 (+)
unnamed: R8.1, U2.6 (-), U2.7
unnamed: C6.2, R9.1, U3.3 (+)
unnamed: R10.1, U3.1, U3.2 (-)
unnamed: C8.2, R11.1, U3.5 (+)
unnamed: R12.1, U3.6 (-), U3.7
OUT_5: R14.1, U1.1, U1.2 (-)

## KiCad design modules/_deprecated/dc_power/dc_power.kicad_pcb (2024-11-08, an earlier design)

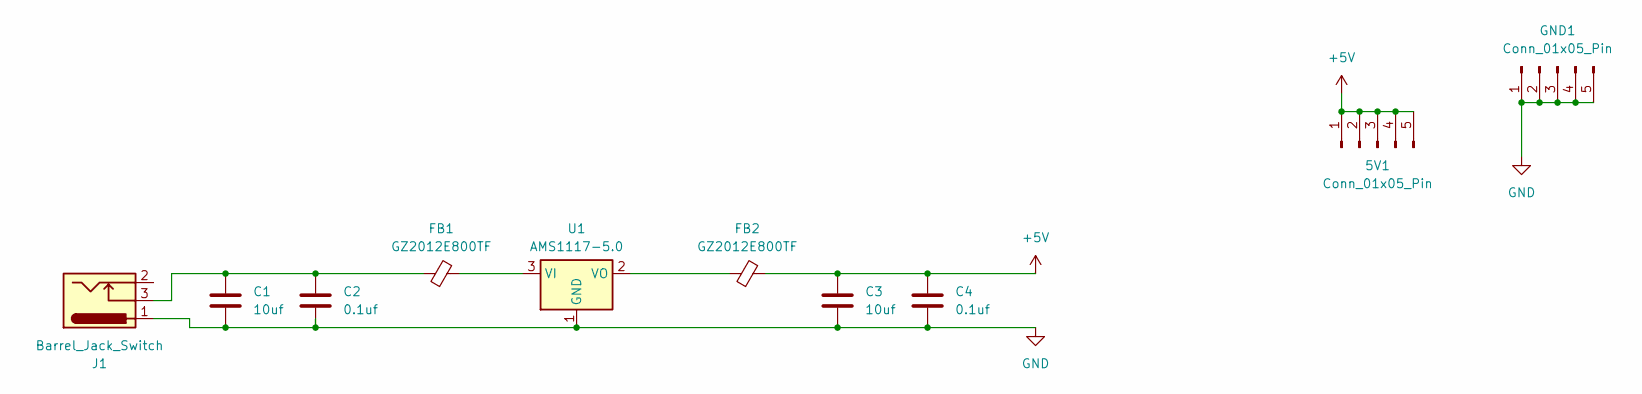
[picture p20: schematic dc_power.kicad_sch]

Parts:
5V1: Conn_01x05_Pin; PinHeader_1x05_P2.54mm_Vertical
C1, C3: 10uf; C_0805_2012Metric
C2, C4: 0.1uf; C_0805_2012Metric
FB1, FB2: GZ2012E800TF; C_0805_2012Metric
GND1: Conn_01x05_Pin; PinHeader_1x05_P2.54mm_Vertical
J1: Barrel_Jack_Switch; DC-182-25A
U1: AMS1117-5.0; SOT-223

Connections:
+5V: 5V1.1, 5V1.2, 5V1.3, 5V1.4, 5V1.5, C3.1, C4.1, FB2.2
GND: C1.2, C2.2, C3.2, C4.2, GND1.1, GND1.2, GND1.3, GND1.4, GND1.5, J1.1, U1.1 (GND)
unnamed: C1.1, C2.1, FB1.1, J1.3
unnamed: FB1.2, U1.3 (VI)
unnamed: FB2.1, U1.2 (VO)

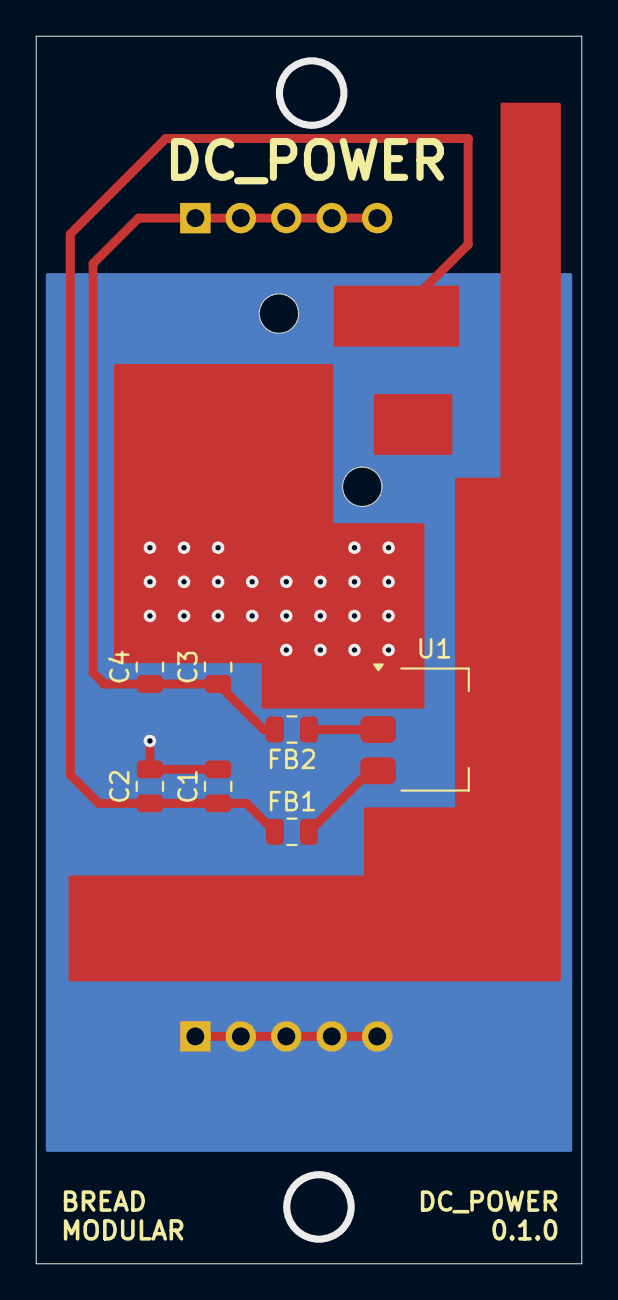
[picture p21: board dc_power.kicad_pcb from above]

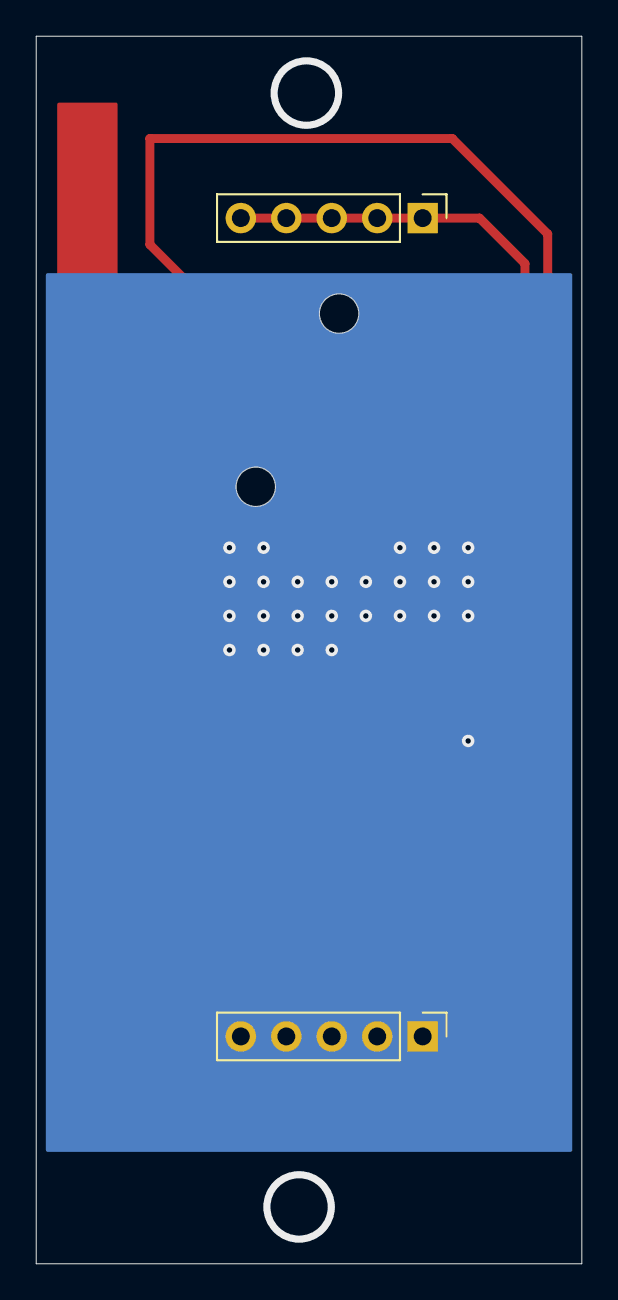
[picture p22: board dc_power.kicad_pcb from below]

Board: 2 copper layers, 30.5 x 68.6 mm, 10 parts (2 on the bottom side), 5 nets.

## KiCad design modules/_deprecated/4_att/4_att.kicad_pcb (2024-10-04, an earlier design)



Board: 2 copper layers, 27.9 x 66.0 mm, 8 parts (2 on the bottom side), 9 nets.

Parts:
1, 2, 3, 4: 100K; Potentiometer_Alpha_RD901F-40-00D_Single_Vertical
5V1: Conn_01x05_Pin; PinHeader_1x05_P2.54mm_Vertical
GND1: Conn_01x05_Pin; PinHeader_1x05_P2.54mm_Vertical
INPUTS: Conn_01x04_Socket; PinSocket_1x04_P2.54mm_Vertical
OUTPUTS: Conn_01x04_Socket; PinSocket_1x04_P2.54mm_Vertical

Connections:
GND: 1.3, 2.3, 3.3, 4.3, GND1.1, GND1.2, GND1.3, GND1.4, GND1.5
IN 1: 1.1, INPUTS.1
IN 2: 2.1, INPUTS.2
IN 3: 3.1, INPUTS.3
IN 4: 4.1, INPUTS.4
OUT 1: 1.2, OUTPUTS.1
OUT 2: 2.2, OUTPUTS.2
OUT 3: 3.2, OUTPUTS.3
OUT 4: 4.2, OUTPUTS.4

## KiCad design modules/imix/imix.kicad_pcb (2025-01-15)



Board: 2 copper layers, 30.5 x 68.6 mm, 35 parts (2 on the bottom side), 22 nets.

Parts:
C1, C2, C4: 0.1uf; C_0402_1005Metric
C3: 100uf; C_1206_3216Metric
GND1: Conn_01x05_Pin; Power_Connector
INPUT1: Conn_01x05_Socket; PinSocket_1x05_P2.54mm_Vertical
OUTPUT1: Conn_01x05_Socket; PinSocket_1x05_P2.54mm_Vertical
R1, R2, R12: 1k; R_0402_1005Metric
R3, R5, R7, R9: 1M; R_0402_1005Metric
R4, R6, R8, R10, R11: 200k; R_0402_1005Metric
R13, R14, R15, R16, R17, R18, R19, R20: 100k; R_0402_1005Metric
RV1, RV2, RV3, RV4: 50k; Potentiometer_RV09
U1, U2, U3: MCP6002-xSN; SOIC-8-1EP_3.9x4.9mm_P1.27mm_EP2.29x3mm
V_SUPPLY1: Conn_01x05_Pin; Power_Connector

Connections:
GND: C1.2, C2.2, C4.2, GND1.1, GND1.2, GND1.3, GND1.4, GND1.5, R2.2, U1.4 (V-), U2.4 (V-), U3.4 (V-)
IN_1: INPUT1.1, R7.2, R14.1
IN_2: INPUT1.2, R9.2, R16.1
IN_3: INPUT1.3, R3.2, R18.1
IN_4: INPUT1.4, R5.2, R20.1
MIXOUT: OUTPUT1.1, OUTPUT1.2, OUTPUT1.3, OUTPUT1.4, OUTPUT1.5, R12.2
unnamed: R4.1, RV3.2
unnamed: R6.1, RV4.2
unnamed: R8.1, RV1.2
unnamed: R10.1, RV2.2
unnamed: R11.2, R12.1, U3.1
unnamed: R13.2, RV1.3, U1.1
unnamed: R15.2, RV2.3, U1.7
unnamed: R17.2, RV3.3, U2.1
unnamed: R19.2, RV4.3, U2.7
unnamed: R13.1, R14.2, U1.2 (-)
unnamed: R15.1, R16.2, U1.6 (-)
unnamed: R17.1, R18.2, U2.2 (-)
unnamed: R19.1, R20.2, U2.6 (-)
unnamed: R4.2, R6.2, R8.2, R10.2, R11.1, U3.2 (-)
V_MID: C3.2, R1.2, R2.1, R3.1, R5.1, R7.1, R9.1, RV1.1, RV2.1, RV3.1, RV4.1, U1.3 (+), U1.5 (+), U2.3 (+), U2.5 (+), U3.3 (+)
V_SUPPLY: C1.1, C2.1, C3.1, C4.1, R1.1, U1.8 (V+), U2.8 (V+), U3.8 (V+), V_SUPPLY1.1, V_SUPPLY1.2, V_SUPPLY1.3, V_SUPPLY1.4, V_SUPPLY1.5

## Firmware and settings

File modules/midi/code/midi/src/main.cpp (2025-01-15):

/* Arduino ATTiny 1616 Pin Map

  0 - PA4
  1 - PA5
  2 - PA6
  3 - PA7
  4 - PB5
  5 - PB4
  6 - PB3, RX
  7 - PB2, TX
  8 - PB1
  9 - PB0
  10 - PC0
  11 - PC1
  12 - PC2
  13 - PC3
  14 - PA1
  15 - PA2
  16 - PA3
*/

#include <SimpleMIDI.h>
#include <SoftwareSerial.h>

#define PIN_RX 6 // PB3
#define PIN_TX 7 // PB2

// Define the Gate Pins
#define GATE_PIN_01 10 // PC0
#define GATE_PIN_02 11 // PC1
#define GATE_PIN_03 12 // PC2
#define GATE_PIN_04 13 // PC3
#define GATE_PIN_05 14 // PA1
#define GATE_PIN_06 15 // PA2
#define GATE_PIN_07 16 // PA3
#define GATE_PIN_08 0 // PA4

// Define IMIDI Pins
#define IMIDI_PIN_01 1 // PA5
#define IMIDI_PIN_02 2 // PA6
#define IMIDI_PIN_03 3 // PA7
#define IMIDI_PIN_04 4 // PB5
#define IMIDI_PIN_05 5 // PB4
#define IMIDI_PIN_06 8 // PB1
#define IMIDI_PIN_07 9 // PB0

// Create a MIDI object
SimpleMIDI MIDI;

SoftwareSerial midiSerialArray[] = {
    SoftwareSerial(-1, IMIDI_PIN_01),
    SoftwareSerial(-1, IMIDI_PIN_02),
    SoftwareSerial(-1, IMIDI_PIN_03),
    SoftwareSerial(-1, IMIDI_PIN_04),
    SoftwareSerial(-1, IMIDI_PIN_05),
    SoftwareSerial(-1, IMIDI_PIN_06),
    SoftwareSerial(-1, IMIDI_PIN_07),
};

int getGatePin(int id) {
  switch (id) {
    case 1:
      return GATE_PIN_01;
    case 2:
      return GATE_PIN_02;
    case 3:
      return GATE_PIN_03;
    case 4:
      return GATE_PIN_04;
    case 5:
      return GATE_PIN_05;
    case 6:
      return GATE_PIN_06;
    case 7:
      return GATE_PIN_07;
    case 8:
      return GATE_PIN_08;
    default:
      return -1;
  }
}

void sendMIDI(byte channel, byte status, byte data1, byte data2) {
  int channelIndex = channel - 1;
  if (channelIndex >= 0 && channelIndex < 7) {
    SoftwareSerial serialCh = midiSerialArray[channelIndex];
    serialCh.write(status); // Send the status byte
    serialCh.write(data1);  // Send the first data byte
    serialCh.write(data2);  // Send the second data byte
  }
}

void setupGates() {
  for (int x = 1; x <= 8; x = x + 1) {
    int gatePin = getGatePin(x);
    pinMode(gatePin, OUTPUT);
    digitalWrite(gatePin, LOW);
  }
}

void setupIMIDI() {
  pinMode(IMIDI_PIN_01, OUTPUT);
  pinMode(IMIDI_PIN_02, OUTPUT);
  pinMode(IMIDI_PIN_03, OUTPUT);
  pinMode(IMIDI_PIN_04, OUTPUT);
  pinMode(IMIDI_PIN_05, OUTPUT);
  pinMode(IMIDI_PIN_06, OUTPUT);
  pinMode(IMIDI_PIN_07, OUTPUT);

  for (int i = 0; i < 7; i++) {
    midiSerialArray[i].begin(31250); // Start each SoftwareSerial at MIDI baud rate
  }
}

void handleNoteOn(byte channel, byte note, byte velocity) {
  int gatePin = getGatePin(channel);
  if (gatePin != -1) {
    digitalWrite(gatePin, HIGH);
  }
  
  sendMIDI(channel, 0x90, note, velocity);
}

// Callback for Note Off messages
void handleNoteOff(byte channel, byte note, byte velocity) {
  int gatePin = getGatePin(channel);
  if (gatePin != -1) {
    digitalWrite(gatePin, LOW);
  }

  sendMIDI(channel, 0x80, note, velocity);
}

// Callback for handling CC messages
void handleControlChange(byte channel, byte controller, byte value) {
  sendMIDI(channel, 0xB0, controller, value);
}

void setup() {
  setupGates();

   // Initialize the MIDI library
  MIDI.begin(31250);

  setupIMIDI();

  Serial.println("MIDI Listening Started!");
}

void loop() {
 if (MIDI.read()) {
    uint8_t type = MIDI.getType();
    uint8_t channel = MIDI.getChannel() + 1;
    uint8_t data1 = MIDI.getData1();
    uint8_t data2 = MIDI.getData2();

    // Debug output
    if (type == MIDI_NOTE_ON) {
      handleNoteOn(channel, data1, data2);
    } else if (type == MIDI_NOTE_OFF) {
      handleNoteOff(channel, data1, data2);
    } else if (type == MIDI_CONTROL_CHANGE) {
      handleControlChange(channel, data1, data2);
    } else {
        // logger.print("Unknown MIDI Data| ");
    }
}
}

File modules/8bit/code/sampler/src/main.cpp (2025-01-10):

#include <Arduino.h>
#include <SoftwareSerial.h>
#include <avr/io.h>
#include <avr/interrupt.h>
#include "utils.h"
#include "SimpleMIDI.h"
#include "ModeHandler.h"
#include "Player.h"
#include "samples/ride.h"
#include "samples/snare.h"
#include "samples/perc.h"
#include "samples/clap.h"
#include "samples/rim.h"
#include "samples/closed_hat.h"
#include "samples/open_hat.h"

#define GATE_PIN PIN_PA7
#define LOGGER_PIN_TX PIN_PB4
#define PIN_CV1 PIN_PA1
#define PIN_CV2 PIN_PA2
#define TOGGLE_PIN PIN_PA4
#define TOGGLE_LED PIN_PA5

SimpleMIDI MIDI;
SoftwareSerial logger = SoftwareSerial(-1, LOGGER_PIN_TX);
ModeHandler modes = ModeHandler(TOGGLE_PIN, 3, 300);

void toggleLED() {
  delay(500);
  digitalWrite(TOGGLE_LED, HIGH);
  delay(500);
  digitalWrite(TOGGLE_LED, LOW);
}

void setupTimer() {
    TCB0.CTRLA |= TCB_ENABLE_bm; // counting value

    // Uses 20Mhz clock & divide it by for here
    // So, 1 tick is 0.1us
    TCB0.CTRLA |= TCB_CLKSEL_CLKDIV2_gc; // clock div by 1

    TCB0.CCMP = 10000000 / (RIDE_SAMPLE_RATE); // Set the compare value
  
    // Enabling inturrupts
    TCB0.CTRLB |= TCB_CNTMODE_INT_gc; // Timer interrupt mode (periodic interrupts)
    TCB0.INTCTRL = TCB_CAPT_bm; // Enable Capture interrupt
    sei();
}

bool playNow = false;
// TCB0 Interrupt Service Routine
ISR(TCB0_INT_vect) {
  playNow = true;

  // Clear the interrupt flag∫
  TCB0.INTFLAGS = TCB_CAPT_bm;
}

void setup() {
  // define the gate pin
  pinMode(GATE_PIN, OUTPUT);
  digitalWrite(GATE_PIN, LOW);

  // Setup Logger
  pinMode(LOGGER_PIN_TX, OUTPUT);
  logger.begin(9600);
  
  // Set the analog reference for ADC with supply voltage.
  analogReference(VDD);
  pinMode(PIN_CV1, INPUT);
  pinMode(PIN_CV2, INPUT);
 
  // DAC0 setup for sending velocity via the PA6 pin
  VREF.CTRLA |= VREF_DAC0REFSEL_4V34_gc; //this will force it to use VDD as the VREF
  VREF.CTRLB |= VREF_DAC0REFEN_bm;
  DAC0.CTRLA = DAC_ENABLE_bm | DAC_OUTEN_bm;
  DAC0.DATA = 0;

  // Setup MIDI
  MIDI.begin(31250);

  // Timer related
  setupTimer();
  
  // Modes
  modes.begin();
  pinMode(TOGGLE_LED, OUTPUT);

  logger.println("MCO 0.2.0 Started!");
}

void pickSound(uint8_t note, uint8_t velocity) {
  // Here we pick sounds for C, D, E, F, G, A, B (regardless of their octave)
  byte soundIndex = note % 12;
  switch (soundIndex)
  {
    case 0:
      startPlayer(0, SNARE_SAMPLE, SNARE_SAMPLE_LENGTH, velocity);
      break;

    case 2:
      startPlayer(2, CLAP_SAMPLE, CLAP_SAMPLE_LENGTH, velocity);
      break;

    case 4:
      startPlayer(4, PERC_SAMPLE, PERC_SAMPLE_LENGTH, velocity);
      break;

    case 5:
      startPlayer(5, RIM_SAMPLE, RIM_SAMPLE_LENGTH, velocity);
      break;

    case 7:
      startPlayer(7, CLOSED_HAT_SAMPLE, CLOSED_HAT_SAMPLE_LENGTH, velocity);
      break;

    case 9:
      startPlayer(9, OPEN_HAT_SAMPLE, OPEN_HAT_SAMPLE_LENGTH, velocity);
      break;

    case 11:
      startPlayer(11, RIDE_SAMPLE, RIDE_SAMPLE_LENGTH, velocity);
      break;
    
    default:
      break;
  }
}

void loop() {
  // parse incoming MIDI messages
   if (MIDI.read()) {
      uint8_t type = MIDI.getType();
      uint8_t channel = MIDI.getChannel();
      uint8_t data1 = MIDI.getData1();
      uint8_t data2 = MIDI.getData2();

      // Debug output
      if (type == MIDI_NOTE_ON) {
        digitalWrite(GATE_PIN, HIGH);
        pickSound(data1, data2);
      } else if (type == MIDI_NOTE_OFF) {
        digitalWrite(GATE_PIN, LOW);
      } else if (type == MIDI_CONTROL_CHANGE) {
          
      } else {
          // logger.print("Unknown MIDI Data| ");
      }
  }

  // mode related code
  if (modes.update()) {
    byte currentMode = modes.getMode();
    if (currentMode == 0) {
      toggleLED();
    } else if (currentMode == 1) {
      toggleLED();
      toggleLED();
    } else if (currentMode == 2) {
      toggleLED();
      toggleLED();
      toggleLED();
    }
  }

  if (playNow) {
    DAC0.DATA = getPlayHead();
    playNow = false;
  }
}

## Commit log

2024-10-04 Add the 4_ATT module
    [4_att.kicad_pcb, 4_att.kicad_sch]
2024-10-04 Add aa module for the buff_mix
    [blank.kicad_pcb, blank.kicad_sch, buff_mix.kicad_pcb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]
2024-10-04 Add the final buff_mix
    [buff_mix.kicad_pcb, buff_mix.kicad_sch]
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2024-10-07 Add the schematic for the PCB
    [line_in.kicad_pcb, line_in.kicad_sch]
2024-10-07 Update the line-in module
    [line_in.kicad_pcb]
2024-10-07 Make sure SMD via are not placed on pads.
    [bom.csv, designators.csv, line_in.csv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]
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2024-10-14 Retouched the Blank Module with new sizes.
    [blank.kicad_pcb]
2024-10-14 Add basic version of 4_mix
    [4_mix.kicad_pcb, 4_mix.kicad_sch]
2024-10-14 Implement the simulation model.
    [4_mix.kicad_sch]
2024-10-15 Updated the core design
    [4_mix.kicad_pcb, 4_mix.kicad_sch]
2024-10-15 Fixed some pcb layout issues.
    [4_mix.kicad_pcb, blank.kicad_pcb, blank.kicad_sch]
2024-10-15 Add the full mixer
    [4_mix.kicad_pcb, 4_mix.kicad_sch]
2024-10-16 Schematics is done. Now it's time for PCB layout.
    [4_mix.kicad_sch]
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2024-10-16 Implemented the PCB design of 4_mix
    [4_mix.kicad_pcb, 4_mix.kicad_sch]
2024-10-16 Change some routing rules.
    [4_mix.kicad_pcb]
2024-10-16 Finalized 4_mix for production
    [4_mix.kicad_pcb]
2024-10-16 Add sockets for the blank project.
    [blank.kicad_pcb, blank.kicad_sch]
2024-10-17 Start working on the new version of line_in
    [bom.csv, designators.csv, line_in.csv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]
2024-10-17 Finalize the core design
    [line_in.kicad_sch]
2024-10-17 Add AudioJacks submodule with KiCad footprints.
    [line_in.kicad_sch]
2024-10-17 Finalize the schematic design
    [line_in.kicad_sch]
2024-10-17 Finished building the line_in module.
    [line_in.kicad_pcb, line_in.kicad_sch]
2024-10-17 Add the line_in 0.3.0 production build
    [line_in.kicad_pcb]
2024-10-18 Add the initial version of the line_out
    [line_out.kicad_pcb, line_out.kicad_sch]
2024-10-18 Finalized the line_out module.
    [line_out.kicad_pcb, line_out.kicad_sch]
2024-10-20 Add BreakoutBoards for popular opamps.
    [BreakoutBoards.kicad_pcb, BreakoutBoards.kicad_sch]
2024-10-20 Finlalized schematic for head_out module.
    [head_out.kicad_pcb, head_out.kicad_sch]
2024-10-20 Finished pcb_design of the head_out
    [head_out.kicad_pcb, head_out.kicad_sch]
2024-10-20 Finialize the design based on actual wattage requirements.
    [head_out.kicad_pcb, head_out.kicad_sch]
2024-10-21 Finalize the head_out module.
    [head_out.kicad_pcb, head_out.kicad_sch]
2024-10-27 Use TL072 the current version has some pops and cracks LM358 could be the issue. So, we are trying TL072
    [4_mix.kicad_pcb, 4_mix.kicad_sch]
2024-10-27 Use MCP6002 in the 4_mix. This provides more headroom due to it's rail-2-rail output.
    [4_mix.kicad_pcb, 4_mix.kicad_sch]
2024-10-28 Add missing production files for 4_mix
    [4_mix.kicad_pcb, 4_mix.kicad_sch]
2024-10-28 Update the basic kidcad app Add simulation support Introduce the version number silkscreen
    [blank.kicad_pcb, blank.kicad_sch]
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2024-10-28 Implement the basic setup. CV support is not done and there are no CV control implemented.
    [jvca.kicad_sch]
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2024-10-29 Fix the simulation a bit.
    [jvca.kicad_sch]
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2024-11-01 Created a RV_09 base Now we can use these inside the breadboard along with some circuit. Or inside BBM Base.
    [rv_base.kicad_pcb, rv_base.kicad_sch]
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2024-11-04 Changed the 6.8k resistor package. Used 0603 package due to availability in JLCPCB
    [ar_env.kicad_pcb, ar_env.kicad_sch]
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2024-11-06 Changed the orientation of the USB C port
    [usb_power-CuBottom.gbr, usb_power-CuTop.gbr, usb_power-EdgeCuts.gbr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]
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2024-11-12 Add Sallen Key capacitors with commonly available caps
    [low_pass.kicad_sch]
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2024-12-07 Add basic noise setup
    [main.cpp]
2024-12-07 Implement noise tone control
    [main.cpp]
2024-12-08 Implement the noise schematics
    [noise.kicad_pcb, noise.kicad_sch]
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2024-12-09 increased the overall delay time of the noise module code
    [main.cpp]
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2024-12-11 Simplify the SVF design with just freq & resonance knobs
    [svf.kicad_sch]
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2024-12-15 cv_math: xpand now uses distance to scale this will make the waveform strech to the highest. It's bottom part won't move anywhere
    [main.cpp]
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2024-12-21 blank:Add opamp & pot as a built-in components These are used in almost all the projects. So, having pre-build components make is easy to get started
    [blank.kicad_pcb, blank.kicad_sch]
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2024-12-24 svf: make it louder & add curve control Now the SVF is 8db louder in general. Now the resonance control active troughout the potentiometer Add the curve support for the freq so, we can target low or 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
    [svf.kicad_pcb, svf.kicad_sch]
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2024-12-27 drive: Remove radio freq. capturing with the gain. This is due to the high-gain nature & the use of non-inverting buffer. Now change it to an inverting buffer & all is gone.
    [drive.kicad_pcb, drive.kicad_sch]
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2024-12-31 base: Add USB power setup to the base
    [base.kicad_pcb, base.kicad_sch]
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2025-01-02 base: update the usb-c socket for proper copper layers
    [base.kicad_pcb]
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2025-01-08 midi: Add support to select MIDI A or B
    [gate_out.kicad_sch, midi.kicad_pcb, midi.kicad_sch]
2025-01-08 hihat: Add MIDI support Now we don't need seperate cables for GATE, Accent & Open Hat. We can control all these via a single MIDI cable.
    [hihat.kicad_pcb, hihat.kicad_sch]
2025-01-10 8bit: Introduce 8bit This is just the same as the current version of MCO. It's an Attiny 1616 powered chip with 8-bit audio output.
    [8bit.kicad_pcb, 8bit.kicad_sch]
2025-01-10 mco: Rebrand the 0.1.0 version as the new MCO. We removed CV support and it's not needed.
    [mco.kicad_pcb, mco.kicad_sch]
2025-01-15 i_mix: Use inverting buffers This will reducing picking up noise coming from cables
    [i_mix.kicad_pcb, i_mix.kicad_sch]
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2025-01-15 base: Remove power extention via TRS cable Even with the regulator, it's noisy. So, instead now we use TRS only for syncing the ground between boards
    [base.kicad_pcb, base.kicad_sch]
2025-01-17 Change uc to SOIC
    Changing the packaging of the micro to SOIC for easier hand soldering.
    [mco.kicad_pcb, mco.kicad_sch]
